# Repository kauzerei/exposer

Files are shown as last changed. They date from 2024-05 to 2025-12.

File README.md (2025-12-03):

# Exposer

Exposure timer for PCB production. 
Can be also used for screen printing or other analog printing techniques.
Quickly knocked together using parts I had laying around.

Pictures are of a previous generation.

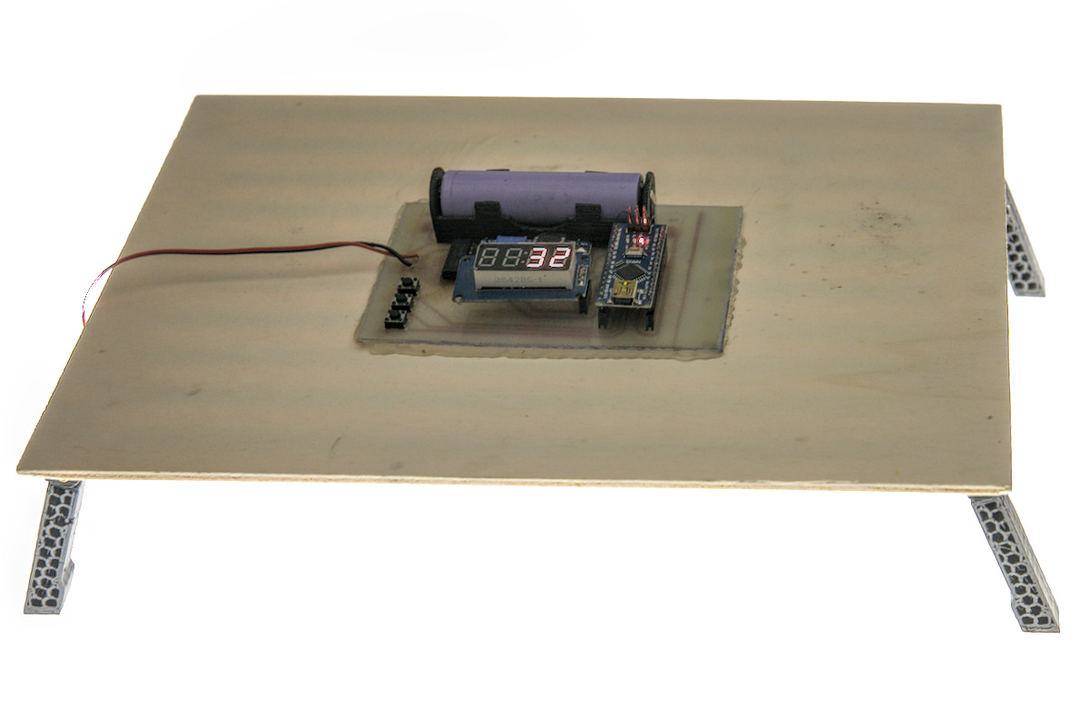
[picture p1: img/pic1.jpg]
pcb side


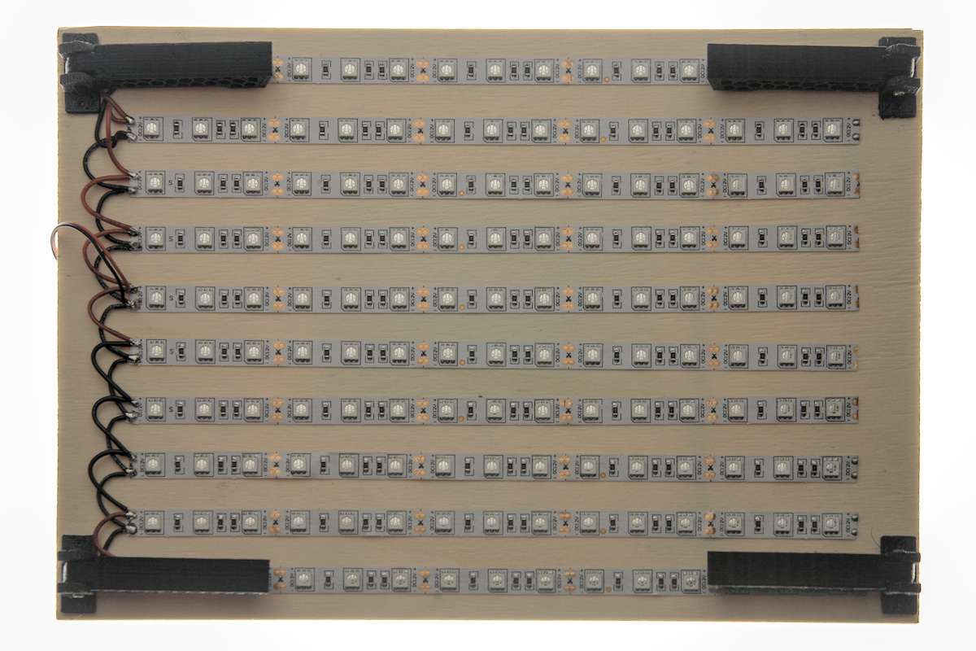
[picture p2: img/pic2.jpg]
led side


## Parts list

TODO: write down particular parts used

- Arduino Nano
- ULN2003 or similar darlington transistor array
- TM1637 4 Digit 7-Segment LED
- 18650 cell with leads or 18650 holder
- Encoder with button
- Switch
- UV LED strip

## Dependency

TM1637Display library is used for driving seven-segment display.
It's the one that comes with Arduino IDE.

https://github.com/avishorp/TM1637

## PCB

The board is one-sided to allow easy fabrication at home.
KiCad project is in ```exposer_pcb```.
Neagtive artwork is in PDF format, but it's better to open the KiCad project for soldering.

## Assembly

3d-print every model once, except the legs, you need four of them.
Put the LED-strips into holding pockets, solder them together and to longer power-in cable.  
Fix the legs with 4mm screws or however you like.
Assemble the PCB.
Don't forget to set the correct voltage on boost converter.
Connect the LEDs to the board and you are ready to go.

## Customizing

You can change the 3d-model even if you don't really know OpenSCAD language.
OpenSCAD has customizer module, in which you can graphically change the parameters.
You can use longer LED strips or more of them.

## Usage

Rotating the encoder changes exposure in relative EV units.
Display shows time in seconds, or denominator of a fraction of a second.
It ```:``` symbol is present on display, it's fraction, if not - whole seconds.
Every step divides or multiplies the exposure time.
Pressing the encoder starts exposure and shows countdown.

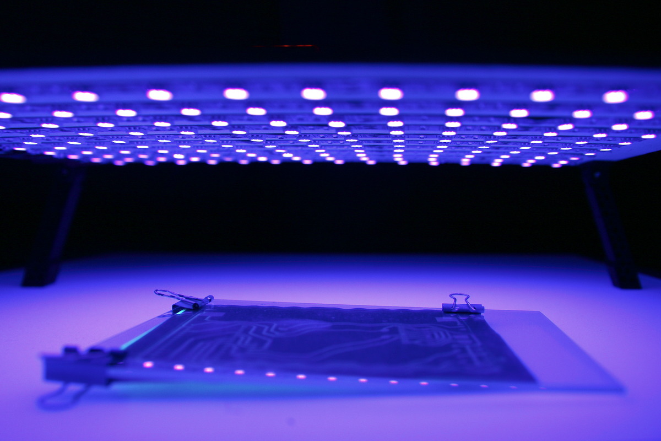
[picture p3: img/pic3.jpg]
exposer shines light on some pcb. this picture makes no sense, to be replaced


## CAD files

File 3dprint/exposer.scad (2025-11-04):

$fn=64;
bsl=1/100;

part="bottom";//[NOSTL_assembly,bottom,foot]
wall=1.2;
angle=10;
thickness=8;
hole=3;
slack=1;

led_width=10.5;
led_length=50;
led_depth=1.2;
led_dist=16.5;
led_strips=4;

box_size=[led_length+4*thickness+2*slack,led_dist*(1+led_strips)];
length=box_size[1]-thickness;

module bottom() {
  translate(-box_size/2) cube([box_size[0],box_size[1],wall]);
  translate([0,-box_size[1]/2,wall]) rotate([90,0,90])linear_extrude(height=led_length,center=true) 
  difference() {
    square([box_size[1],led_depth]);
    for (shift=[led_dist:led_dist:box_size[1]-1]) translate([shift,0]) polygon([[-led_width/2,0],[led_width/2,0],[0,led_width/2]]);
  }
  for (xflip=[[0,0],[1,0]],yflip=[[0,0],[0,1]]) mirror(xflip) mirror(yflip) translate(-box_size/2) eyelet();
}

module eyelet() {
  difference() {
    union() {
      translate([thickness/2,0,wall])cube([thickness,thickness/2,thickness+slack]);
      translate([thickness/2,0,wall])cube([thickness,thickness,thickness/2+slack]);
      translate([thickness/2,thickness/2,wall+thickness/2+slack])rotate([0,90,0])cylinder(d=thickness,h=thickness);

    }
    translate([thickness/2-bsl,thickness/2,wall+thickness/2+slack])rotate([0,90,0])cylinder(d=hole,h=thickness+2*bsl);
  }
}

module foot() {
  difference() {
    hull() {
      cylinder(d=thickness,h=thickness);
      translate([length-thickness,0,0]) cylinder(d=thickness,h=thickness);
    }
  translate([0,0,-bsl])cylinder(d=hole,h=thickness+2*bsl);
  rotate([0,0,angle])translate([-thickness/2-bsl,-length/2,thickness/2]) cube([thickness+2*bsl,length,thickness]);
  translate([-thickness/2-bsl,-length/2,thickness/2]) cube([thickness+2*bsl,length,thickness]);
  }
}
if (part=="foot") foot();
if (part=="bottom") bottom();
if (part=="NOSTL_assembly") {
  bottom();
  translate([2*thickness,thickness/2,wall+thickness/2])
  translate(-box_size/2) rotate([angle,0,0])rotate([0,-90,0])foot();

}

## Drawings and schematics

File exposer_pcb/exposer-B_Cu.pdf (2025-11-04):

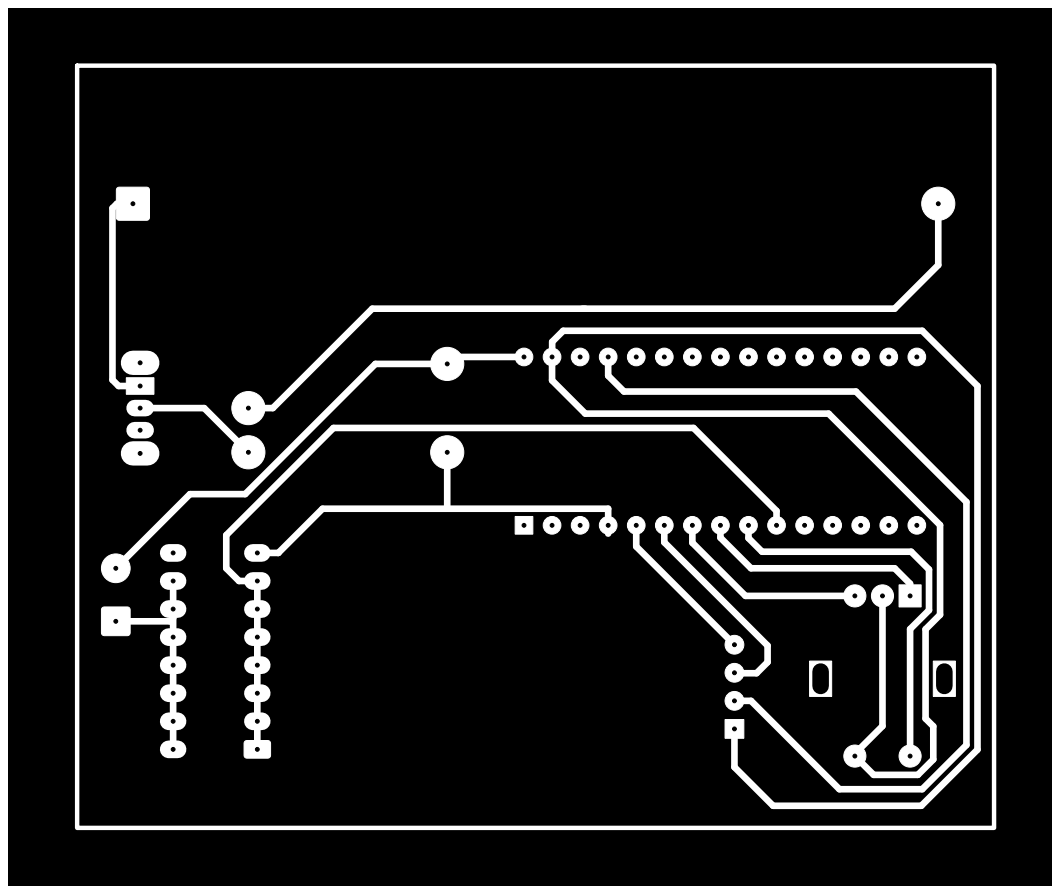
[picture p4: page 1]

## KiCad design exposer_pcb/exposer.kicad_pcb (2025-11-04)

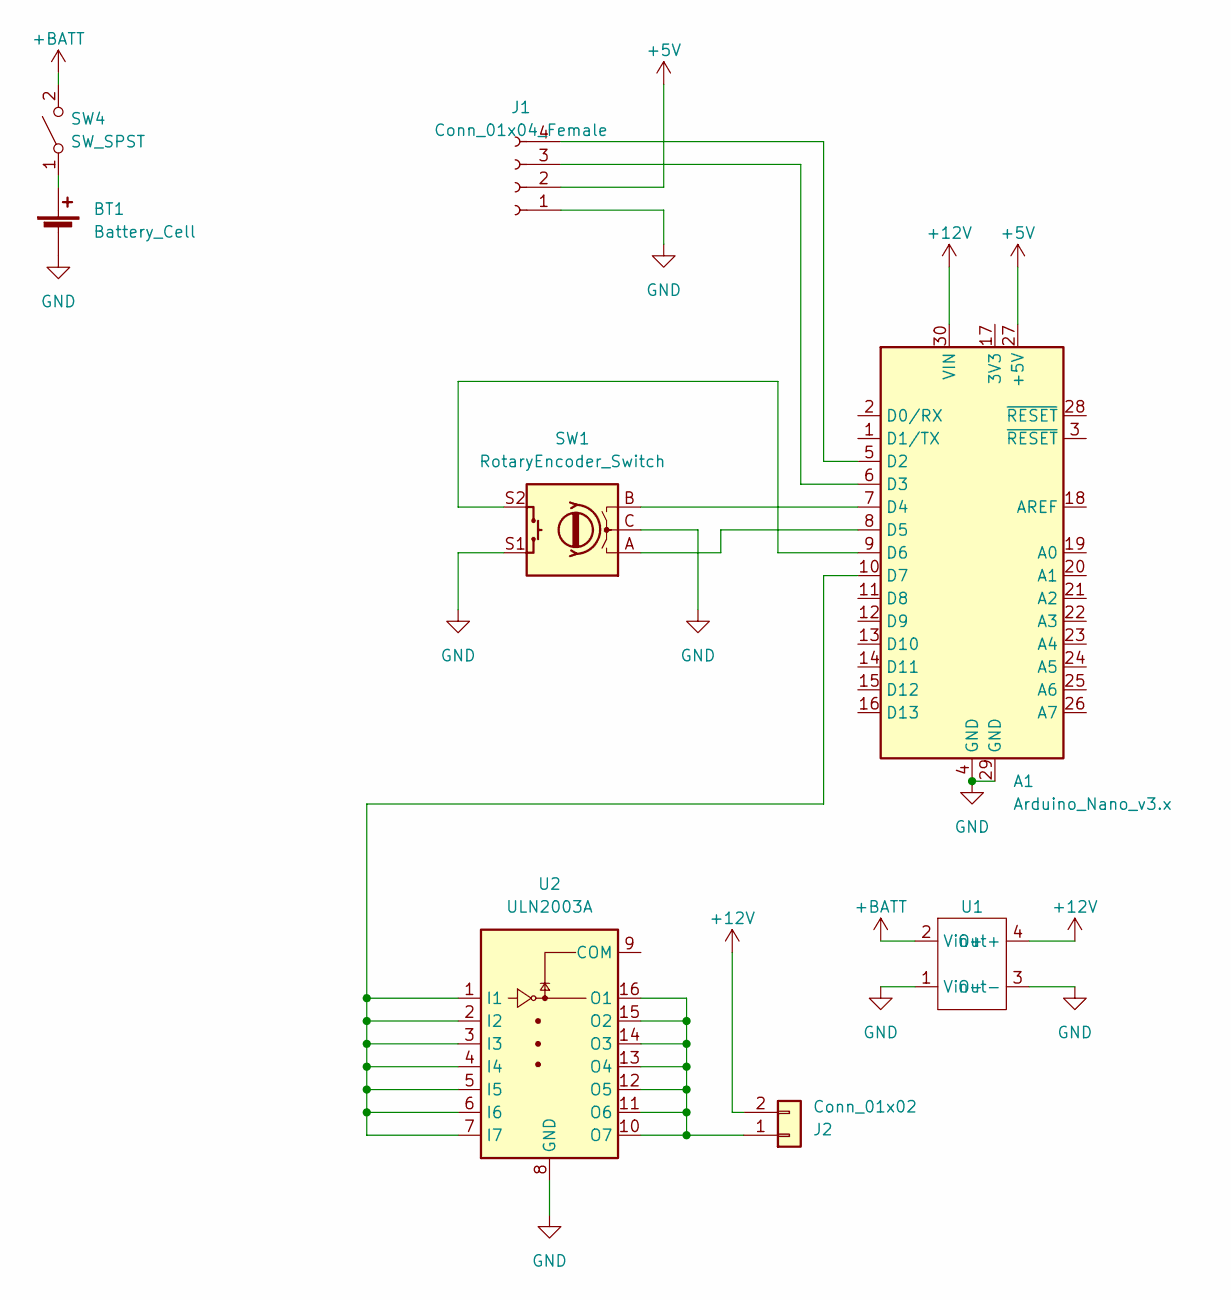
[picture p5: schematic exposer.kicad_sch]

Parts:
A1: Arduino_Nano_v3.x; Arduino_Nano
BT1: Battery_Cell; BatteryHolder_MPD_BH-18650-PC
J1: Conn_01x04_Female; PinSocket_1x04_P2.54mm_Vertical
J2: Conn_01x02; SolderWire-0.75sqmm_1x02_P4.8mm_D1.25mm_OD2.3mm
SW1: RotaryEncoder_Switch; RotaryEncoder_Alps_EC11E-Switch_Vertical_H20mm
SW4: SW_SPST; SW_Slide_SPDT_Straight_CK_OS102011MS2Q
U1: dc-dc module
U2: ULN2003A; DIP-16_W7.62mm_LongPads

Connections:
+5V: A1.27 (+5V), J1.2
+12V: A1.30 (VIN), J2.2, U1.4 (Out+)
+BATT: SW4.2 (B), U1.2 (Vin+)
GND: A1.4 (GND), A1.29 (GND), BT1.2 (-), J1.1, SW1.C, SW1.S1, U1.1 (Vin-), U1.3 (Out-), U2.8 (GND)
unnamed: A1.5 (D2), J1.4
unnamed: A1.6 (D3), J1.3
unnamed: A1.7 (D4), SW1.B
unnamed: A1.8 (D5), SW1.A
unnamed: A1.9 (D6), SW1.S2
unnamed: A1.10 (D7), U2.1 (I1), U2.2 (I2), U2.3 (I3), U2.4 (I4), U2.5 (I5), U2.6 (I6), U2.7 (I7)
unnamed: BT1.1 (+), SW4.1 (A)
unnamed: J2.1, U2.10 (O7), U2.11 (O6), U2.12 (O5), U2.13 (O4), U2.14 (O3), U2.15 (O2), U2.16 (O1)

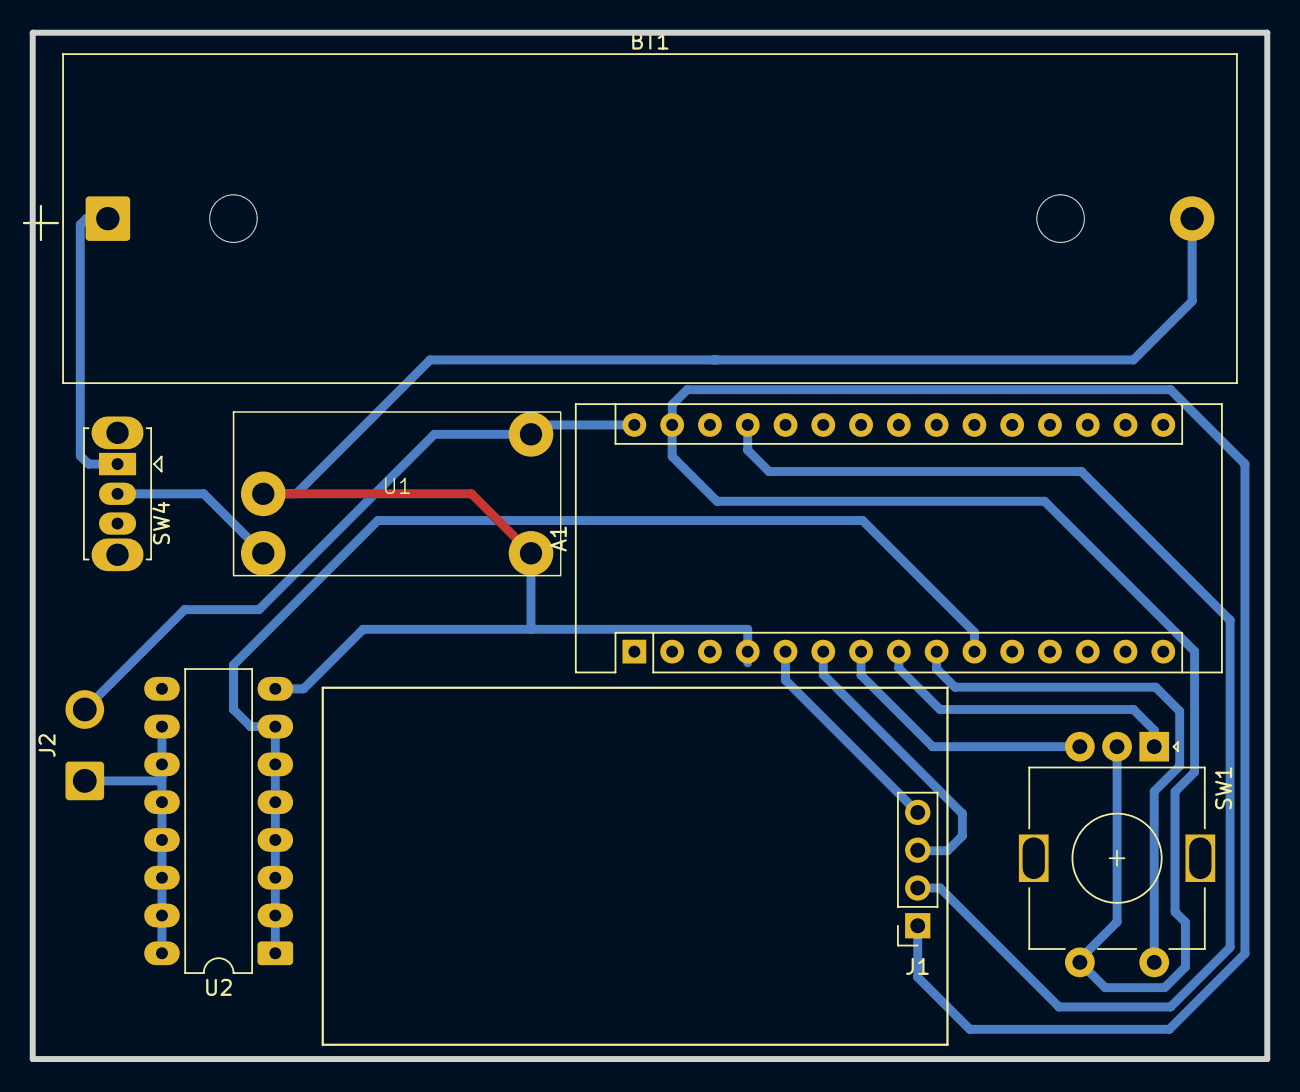
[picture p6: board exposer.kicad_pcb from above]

Board: 2 copper layers, 83.0 x 69.0 mm, 8 parts (0 on the bottom side), 12 nets.

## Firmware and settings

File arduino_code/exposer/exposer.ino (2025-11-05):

// Time relay for exposure unit.
//
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
#include <TM1637Display.h> //https://github.com/avishorp/TM1637

const char led_out=7;
const char button=6;
const char encoder_b=5;
const char encoder_a=4;
const char display_clk=2;
const char display_dio=3;
unsigned long debounce=0;
byte ei=10;
double sec=1;
uint8_t data[] = { 0xff, 0xff, 0xff, 0xff };
uint8_t blank[] = { 0x00, 0x00, 0x00, 0x00 };
unsigned long time;
  
TM1637Display display(display_clk, display_dio);

ISR (PCINT2_vect){ // PCINT2_vect: interrupt vector for PORTD
  //if (digitalRead(encoder_a)&&digitalRead(encoder_b)) ei=ei-1;
  //if (digitalRead(encoder_a)&&!digitalRead(encoder_b)) ei=ei+1;
  if (millis()>debounce && (PIND&(1<<4))) {
    if ((PIND&(1<<5))) ei--;
    else ei++;
    debounce=millis()+20;
  }
}

void setup() {
  pinMode(led_out,OUTPUT);
  pinMode(encoder_a,INPUT_PULLUP);
  pinMode(encoder_b,INPUT_PULLUP);
  pinMode(button,INPUT_PULLUP);
  digitalWrite(led_out,LOW);
  display.setBrightness(0x0f);
  PCICR = (1<<PCIE2);    // enable PCINT[23:16] interrupts
  PCMSK2 = (1<<PCINT20); // D4 = PCINT20
}

void showtime(byte ei) {
  if (ei>10) display.showNumberDec(2<<(ei-11));
  else if (ei==10) display.showNumberDec(1);
  else display.showNumberDecEx(2<<(9-ei),0b11100000);
  }

void loop() {
  showtime(ei);
  if (digitalRead(button)==LOW) {
    time=millis();
    digitalWrite(led_out,HIGH);
    while (millis()-time<pow(2,ei-10)*1000)
    display.showNumberDec((millis()-time)/1000-pow(2,ei-10));
    digitalWrite(led_out,LOW);
    delay(500); //implement this better someday maybe
  }
}

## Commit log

2024-05-16 add switch. reorganize
    [exposer.kicad_pcb, exposer.kicad_sch]
2024-05-16 3d printed parts
    [foldable_foot.scad, foldable_foot_foot.stl, foldable_foot_hinge.stl]
2024-05-16 clean up kicad backups
2025-11-04 3d model update
    [exposer.scad, foldable_foot_foot.stl, foldable_foot_hinge.stl]
2025-11-04 encoder pcb
    [exposer.dsn, exposer.kicad_pcb, exposer.kicad_sch]
2025-11-04 screen was upside down
    [exposer.kicad_pcb]
2025-11-04 code works with encoder
2025-11-12 agitating thingy
    [agitator_pcb.kicad_pcb, agitator_pcb.kicad_sch]
2025-11-16 model seems fine
    [agitator_pcb.kicad_pcb, agitator_pcb.kicad_sch]
2025-11-16 forgot to actually add model lol
    [rocker.scad]
2025-11-16 more betterer modl
    [rocker.scad]
2025-11-17 model tuning
    [rocker.scad]
2025-11-17 pcb optimisation
    [agitator_pcb.kicad_pcb, agitator_pcb.kicad_sch]
2025-11-25 more stable mechanics, some fabrication changes
    [rocker.scad]
2025-12-03 separated from lab rocker repo
    [agitator_pcb.kicad_pcb, agitator_pcb.kicad_sch, rocker.scad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]

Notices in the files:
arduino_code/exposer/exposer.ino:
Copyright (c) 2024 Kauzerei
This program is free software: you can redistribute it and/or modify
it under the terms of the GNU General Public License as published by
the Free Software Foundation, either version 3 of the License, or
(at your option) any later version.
